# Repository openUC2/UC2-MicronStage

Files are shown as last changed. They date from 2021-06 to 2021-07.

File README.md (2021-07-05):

<p align="left">

</p>

# openUC2 MicronStage
---

This repository will help you to set up a very simple yet powerful xy-stage for your UC2-based microscope experiments, where manipulating the region of interest (ROI) in X/Y at a micrometer level using NEMA stepper motors becomes important.

The electronics are based on the [GRBL](https://github.com/grbl/grbl)-firmware and can be controlled either through an Arduino Shield (e.g. CNC Shield v3) controlled by a Raspberry Pi/Nvidia Jetson/laptop or a dedicated CNC/3D printing electronics (e.g. MKS CLS). Curious to see what this looks like? Keep scrolling!

<p align="center">
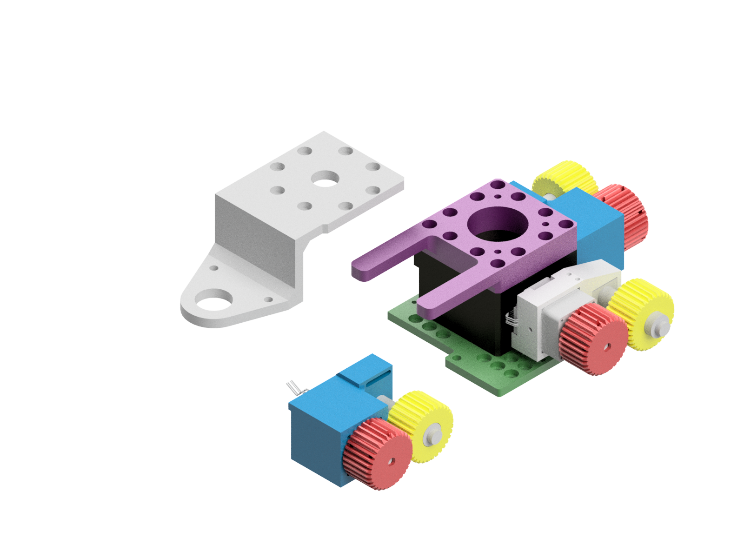
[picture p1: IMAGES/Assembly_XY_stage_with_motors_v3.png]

</p>

This stage can be used for diffrent experiments. We have successfully used it for Ptychography, where micrometer stage manipulation is of importance. Similarly, we use it for autonomously operating fluorescence microscopes. A complete tutorial can be found in the [core UC2 repository](https://github.com/openUC2/UC2-GIT/tree/master/APPLICATIONS/APP_Fluorescence_Microscope_infinity)

Depending on the settings of the [GRBL](https://github.com/grbl/grbl)-controller you can achieve <1µm resolution with the stage! Adding an additional optical encoder by means of a camera (e.g. Raspicam) + microscope objective lens, the open-loop stage can be used as a closed-loop stage with very high precision. More about this will follow soon!

The overall price is in the range under 300€.

The stage on top of a fluorescence microscope:

<p align="center">

</p>

***Features:***

- Move samples plate in XY at high resolution
- NEMA11-based mechanism
- Fast scanning
- Very precise
- Whole setup <300€ in parts
- Easy to assemble
- Limited number of parts (3D printed + off-the-shelf components)
- Minimum of tools required
- Use GRBL as the motion protocol

# Table of Content

- **[Electronics](#-electronics)**
- **[Software](#-software)**
- **[Hardware](#-hardware)**
- **[Bill of materials](#-results)**
- **[Results](#-results)**

## In-Action

You can directly control the microscope from the Opentrons Jupyter notebook. We have collected some notebooks showing its control in the folder [./PYTHON](./PYTHON). This way it becomes very simple to plan experiments which involve both, pipetting and imaging.

<p align="center">

</p>

# SOFTWARE

We offer different ways to control the stage!

## Openflexure

**Warning:** This is still under strong development. We derived the software to control the GRBL-based XYZt stage from the [Openflexure microscope project](https://gitlab.com/beniroquai/openflexure-microscope-server) by Bowman et al.
Instead of using a Raspberry Pi camera, we use an Nvidia Jetson Nano singleboard computer and run a customized version of the OFM server that can control the GRBL board and the monochrome CMOS camera.

A detailed set of instructions for installing the Openflexure Server (OFM Server) will be found in a dedicated README_SOFTWARE.md (it is under construction...). In case you want a preinstalled image, please contact us!

## Octopi-Research

We have written a small device adapter for the Octopi research developed for the SQUID project from the [PrakashLab](https://squid-imaging.org/7bad36b7a9b44cacb1fe1580b39e05d8).
Please have a look in this [repository](https://github.com/beniroquai/octopi-research)

## Custom Python code

We also provide a small code example for driving the code using a python driver. Please refer to the Jupyter Notebook and the package in the folder [PYTHON](./PYTHON).

# HARDWARE

Below we describe how the XY Stage can be build and assembled in order to replicate the whole system as shown in the rendering above. One needs additional parts that can be found in the original [openUC2 repository](https://github.com/bionanoimaging/UC2-GIT).

## Bill of material

Below you will find all components necessary to build this device

### 3D printing files

All these files need to be printed. We used a Prusa i3 MK3 using PLA Prusament (Galaxy Black) at layer height 0.3 mm and infill 80%.

|  Type | Details  |  Price | Link  |
|---|---|---|---|
| Sample Holder |  (optional) Sample holder with lowered base which adapts to XY stage |  0.04 € | [Assembly_XY_stage_with_motors_v3_cellSTORM_UC2_Sample_arm_ptycho.stl](./STL/Assembly_XY_stage_with_motors_v3_cellSTORM_UC2_Sample_arm_ptycho.stl)  |
| Sample Holde | Sample holder with staight base which adapts to XY stage  |  4 € | [Assembly_XY_stage_with_motors_v3_30_XY_Sample_arm_v3.stl](./STL/Assembly_XY_stage_with_motors_v3_30_XY_Sample_arm_v3.stl)  |
| Baseplate | Adapts the XY-stage to the UC2 cubes |  4 € | [Assembly_XY_stage_with_motors_v3_cellSTORM_UC2_Laser_base.stl](./STL/Assembly_XY_stage_with_motors_v3_cellSTORM_UC2_Laser_base.stl)  |
| Motor mount | Adapts the motor to the stage |  4 € | [Assembly_XY_stage_with_motors_v3_30_Mount_Nema_Motor_attachement_for_XYstage_v3.stl](./STL/Assembly_XY_stage_with_motors_v3_30_Mount_Nema_Motor_attachement_for_XYstage_v3.stl)  |
| Gear 2 | Gear for micrometer screw |  4 € | [Assembly_XY_stage_with_motors_v3_cellSTORM_UC2_motorized_micrometer_gear2_1.stl](./STL/Assembly_XY_stage_with_motors_v3_cellSTORM_UC2_motorized_micrometer_gear2_1.stl)  |
| Gear 1 | Gear for motor |  4 € | [Assembly_XY_stage_with_motors_v3_cellSTORM_UC2_motorized_micrometer_gear1_2.stl](./STL/Assembly_XY_stage_with_motors_v3_cellSTORM_UC2_motorized_micrometer_gear1_2.stl)  |

### Additional parts

#### XY Stage from Aliexpress

We tested many different variants, where many were not really reproducible by means of whole positions and linear guiding quality. Finally we decided to buy a couple of these stages and are very happy with them!
The `XY60-C` costs between 40-50€ and compares to a `Thorlabs LX20`stage (820€).

<p align="center">

</p>

It is available from this [Aliexpress shop](https://de.aliexpress.com/item/4000801621380.html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,searchweb201602_,searchweb201603). Search for "XY Axis 60*60mm Trimming Station Manual Displacement Platform Linear Stage Sliding Table XY60-C XY60-R,XY60-LM LY60 Cross Rail"

From the website the following information is available:

***Feature:***

```
1. Using mobile cross roller guides, enabling high-precision, smooth
2. The main body made of aluminum alloy, light weight, suitable to be built for other devices
```

***Parameter:***
```
1. Direction of movement: X Y axis direction
2. Body material: Aluminium
3. Drive: differential head
4. The table size: 60x60mm
5. Table thickness: 36mm/30mm
6. Stroke: ± 6.5mm（Customizable ±12.5,if you need,contact us）
7. Load: 49N (5kgf)
8. Minimum scale: 0.01mm
9. Accuracy class: 0.01mm
10. Parallelism: 0.06mm
11. Weight: 0.48kg
```

#### Additional parts

This is used in the current version of the setup

|  Type | Details  |  Price | Link  |
|---|---|---|---|
| MKS DLC CNC  (NEMA Motors) | Controller Electronics for NEMA motors and Laser |  25 € | [Roboter-Baukasten](https://www.roboter-bausatz.de/p/mks-dlc-cnc-lasergravierer-mainboard-grbl)  |
| M3, M4 Screws | Screw Set |  12 € | [Ebay](https://www.ebay.de/itm/Schrauben-Set-520tlg-Edelstahl-Schrauben-Muttern-M3-M4-M5-Linsenkopfschrauben/383726480774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)  |
| yourDroid Netzteil 12V 3A 5,5x2,1mm DC-Stecker | Power  Supply 12V |  6,45 € | [Roboter-Baukasten](https://www.roboter-bausatz.de/)  |
| 3x A4988 Schrittmotorentreiber	RBS10232 | Stepper Driver |  0,99 € | [Roboter-Baukasten](https://www.roboter-bausatz.de/)  |
| Spring | Diameter: 5mm, 15mm long |  0,99 € | [Roboter-Baukasten](https://www.roboter-bausatz.de/)  |
| Nema11 Motor | Steppermotor |  23 € | [Eckstein](https://eckstein-shop.de/Pololu-Stepper-Motor-NEMA-11-Bipolar-200-Steps-Rev-2832mm-38V-067-A-Phase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)  |

### Assembly of the XY Stage

***1.*** *These are the parts needed for the XY-stage*

<p align="center">
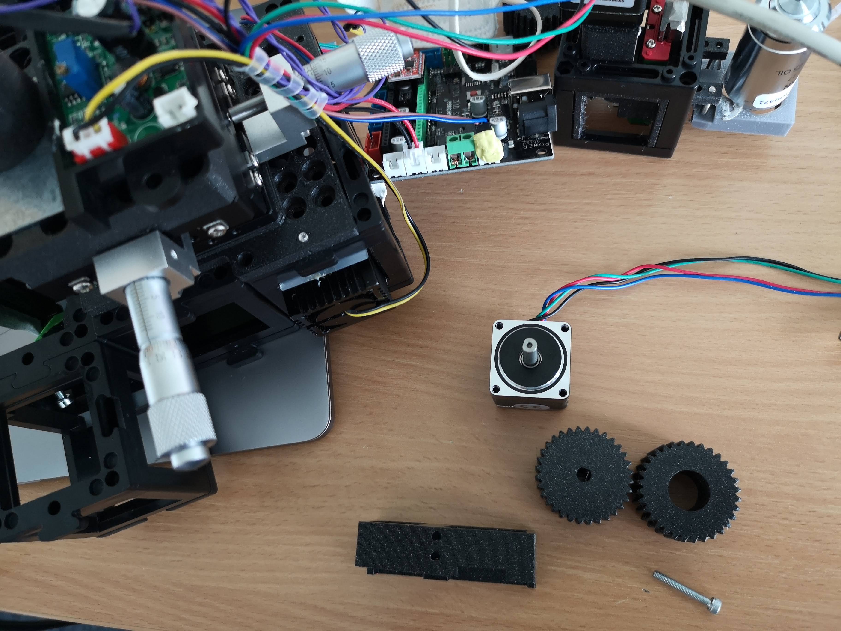
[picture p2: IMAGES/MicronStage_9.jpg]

</p>

***2.*** *Start by removing the micrometre with the screws for one axis*

<p align="center">
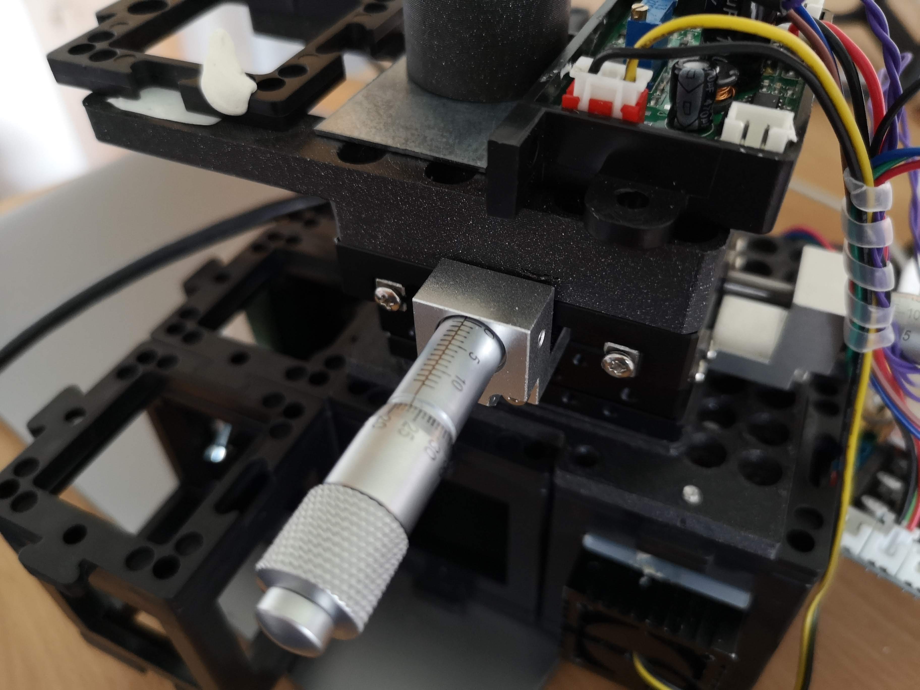
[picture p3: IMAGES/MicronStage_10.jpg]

</p>

***3.*** *Try to add something which blocks the rail from snapping back (e.g. screwdriver)*

<p align="center">
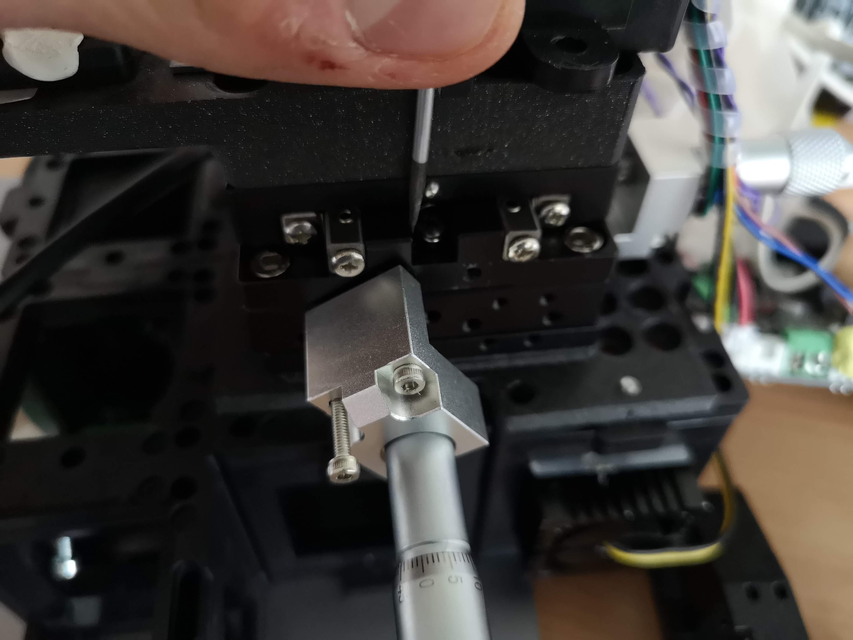
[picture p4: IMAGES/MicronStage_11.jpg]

</p>

***4.*** *Add the micrometer screw to the motor adapter ad add a screw at a side to mount it (M3x8mm)*

<p align="center">
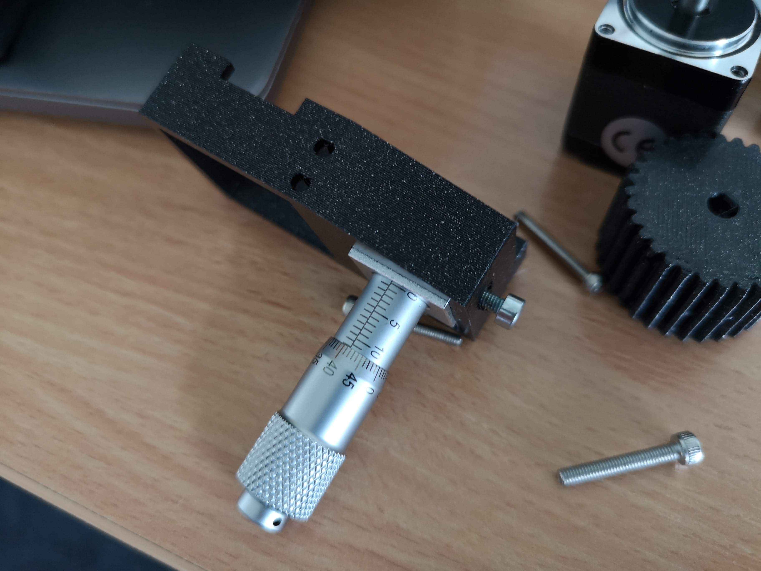
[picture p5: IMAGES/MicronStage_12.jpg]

</p>

***5.*** *Add the motor to the adapter*

<p align="center">
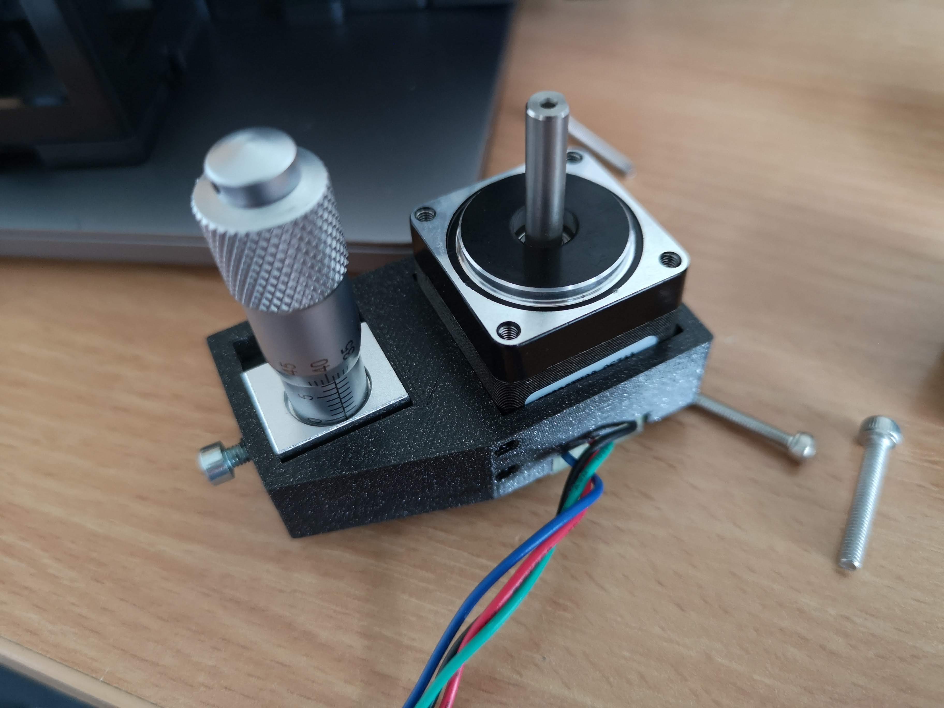
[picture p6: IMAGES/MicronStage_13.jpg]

</p>

***5.1 (optional)*** *Add M3 screws to have a better mounting of the motor*

<p align="center">
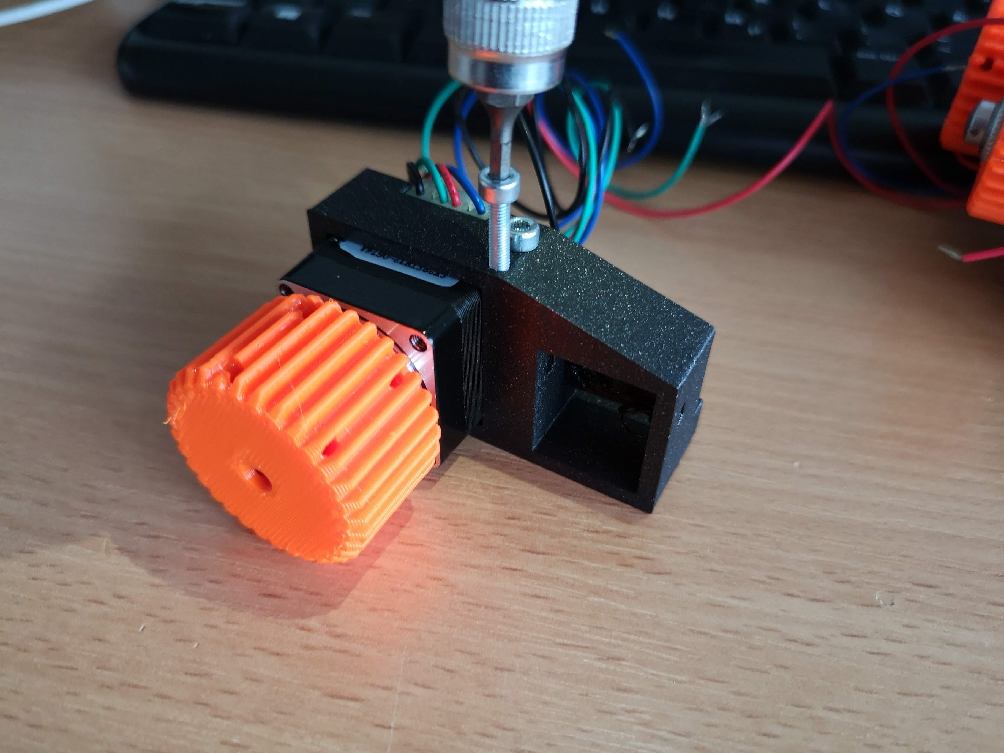
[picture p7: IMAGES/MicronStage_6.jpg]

</p>

***6.*** *Mount the gears*

<p align="center">
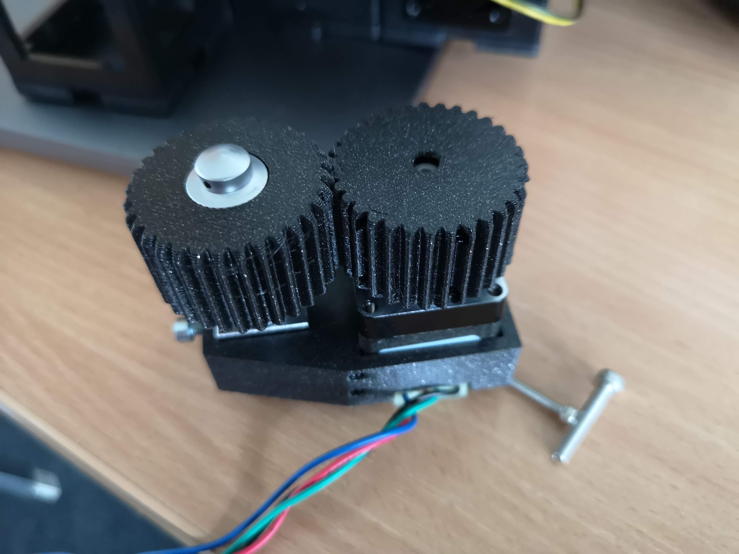
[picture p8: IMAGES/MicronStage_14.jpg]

</p>

***6.1*** *Fix the gears with screws (M3 - headless)*
<p align="center">
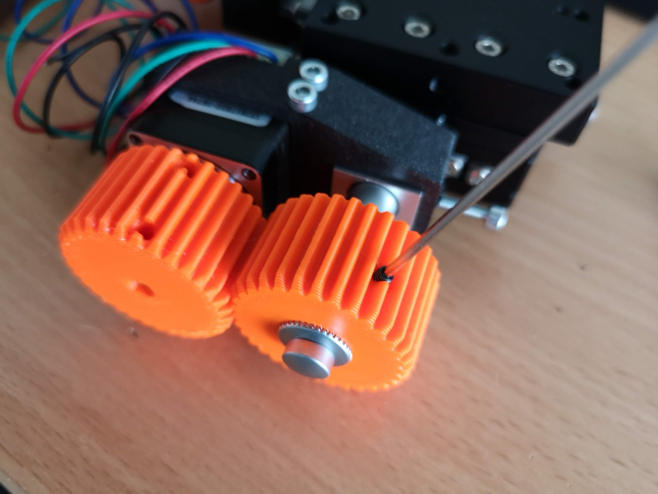
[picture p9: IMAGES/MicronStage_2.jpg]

</p>

***7.*** *Mount the assembly back on the XY-stage with the M2.5 screws*

<p align="center">
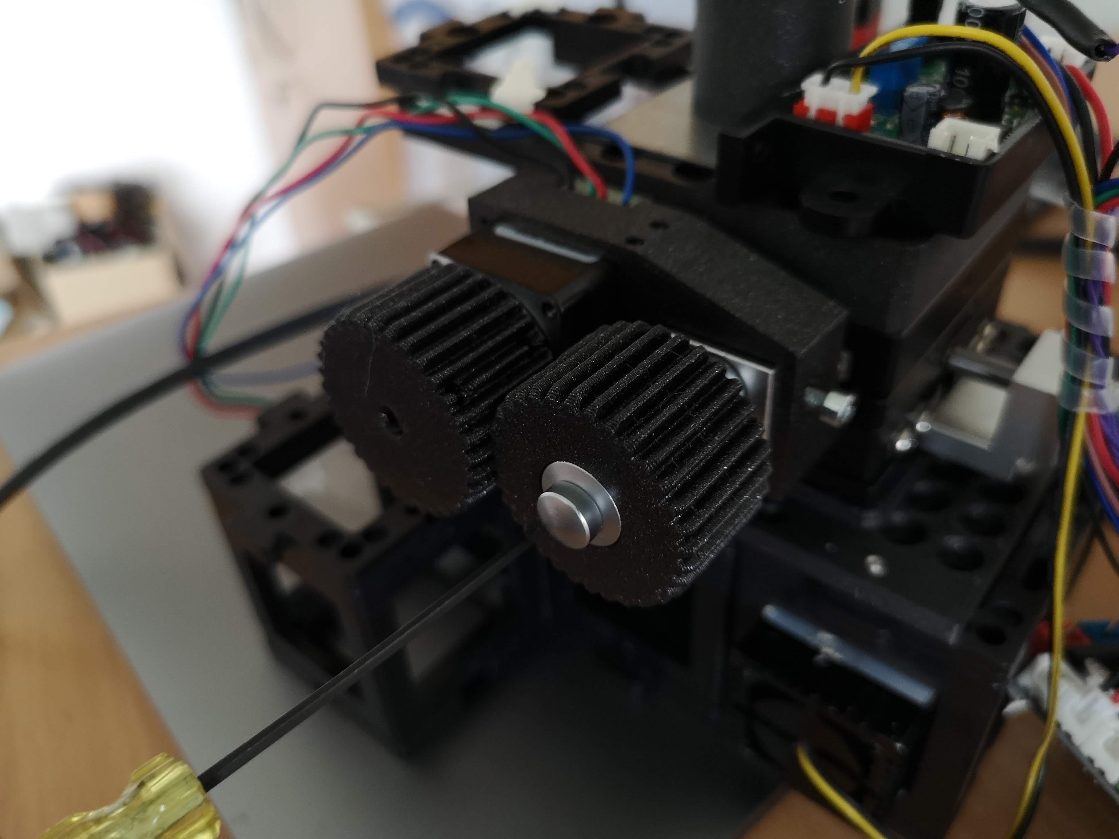
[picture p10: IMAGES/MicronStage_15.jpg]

</p>

***7.1*** *Does it look like this?*
<p align="center">
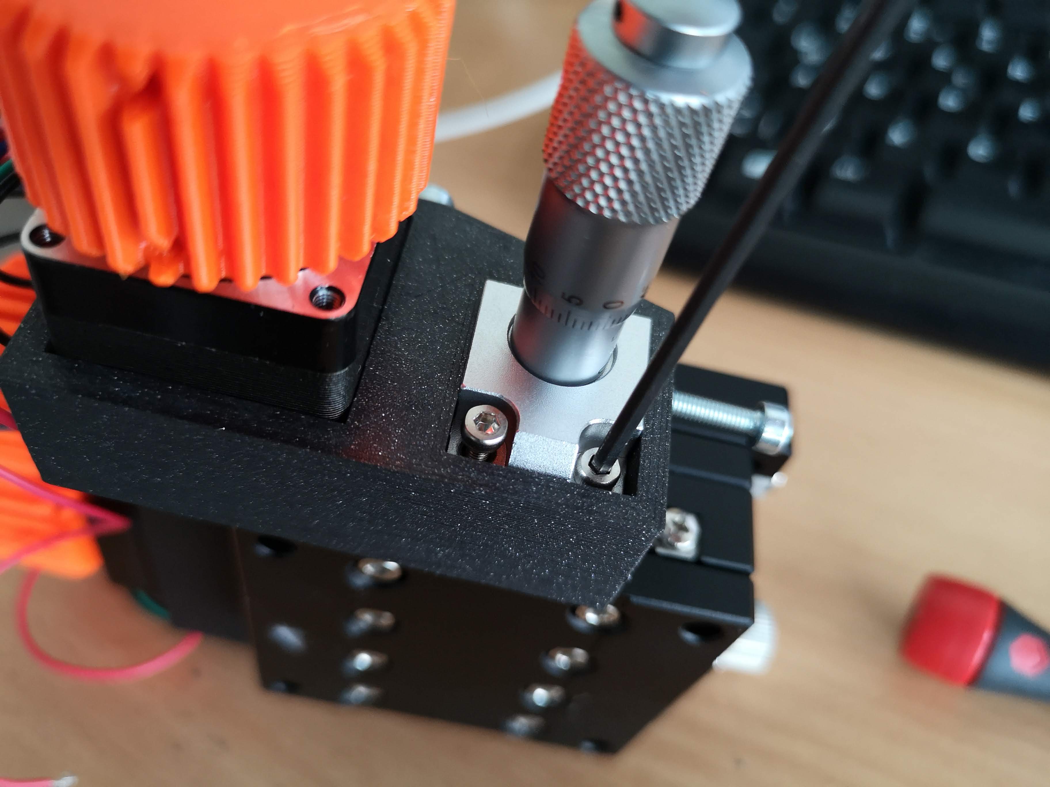
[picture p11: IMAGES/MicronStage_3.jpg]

</p>

***8.*** *Repeat it for the second axis and mount the sample adapter (M4)*

<p align="center">
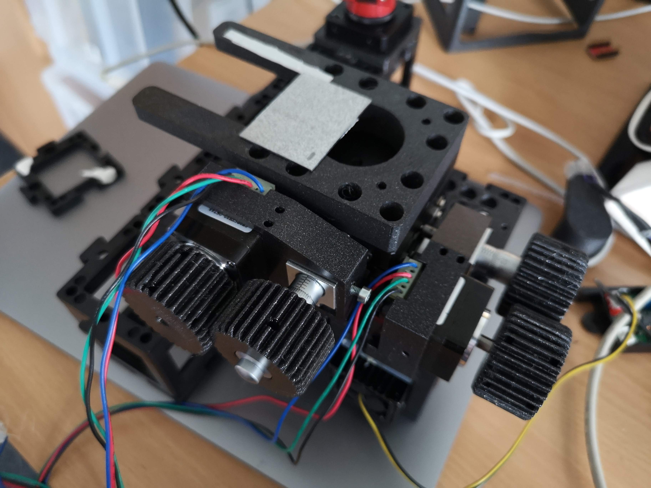
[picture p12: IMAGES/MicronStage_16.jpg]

</p>

***9. (optional)*** *Add the printed baseplate to the XY-stage - then screw the UC2 puzzle-piece baseplates to the printed baseplate of the XY-stage*

<p align="center">
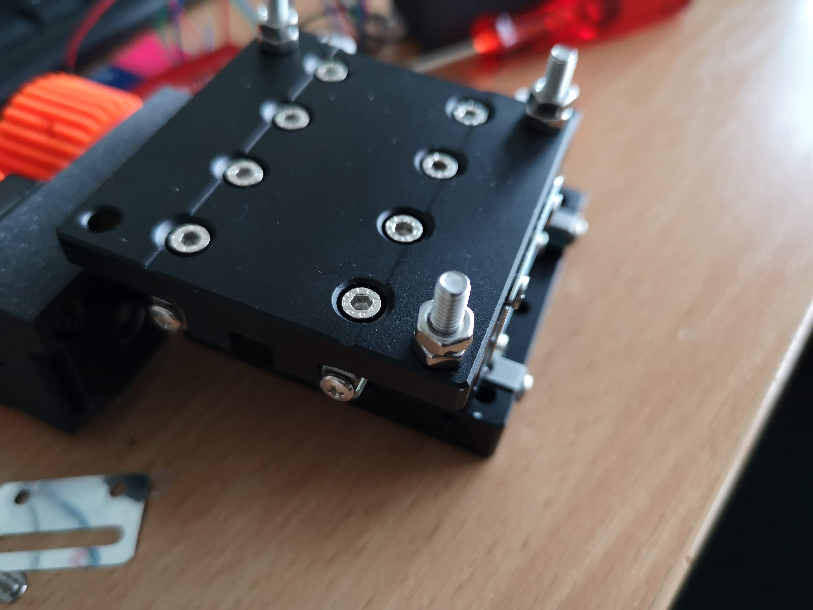
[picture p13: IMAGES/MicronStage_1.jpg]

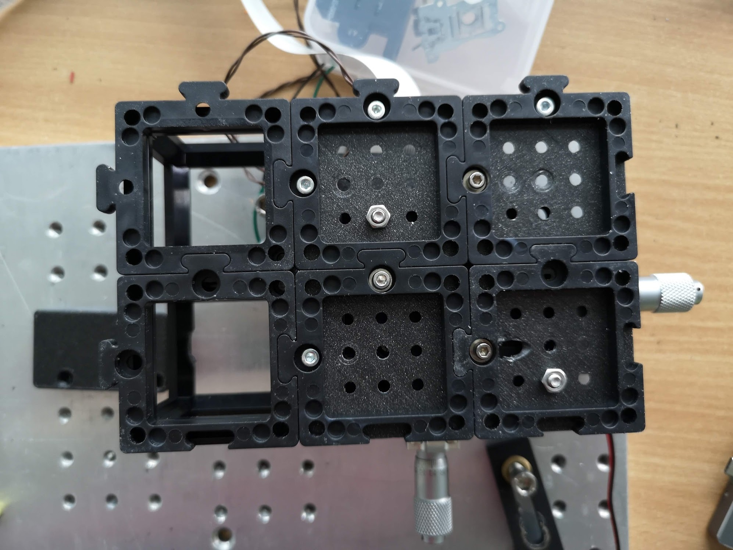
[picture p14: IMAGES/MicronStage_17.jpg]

</p>

## Showcase

Some results will show up here soon.

<p align="center">

</p>

***Fig 1.*** *Fluorescent cells (HeLa) moved in XY/Z This is actually a very bad example ;-)*

<p align="center">

</p>

***Fig 2.*** *Ptychography measurements of a USAF chart scanned through a beam*

## Get Involved

This project is open so that anyone can get involved. You don't even have to learn CAD designing or programming. Find ways you can contribute in  [CONTRIBUTING](https://github.com/openUC2/UC2-GIT/blob/master/CONTRIBUTING.md)

## License and Collaboration

This project is open-source and is released under the CERN open hardware license. Our aim is to make the kits commercially available.
We encourage everyone who is using our Toolbox to share their results and ideas, so that the Toolbox keeps improving. It should serve as a easy-to-use and easy-to-access general purpose building block solution for the area of STEAM education. All the design files are generally for free, but we would like to hear from you how is it going.

You're free to fork the project and enhance it. If you have any suggestions to improve it or add any additional functions make a pull-request or file an issue.

Please find the type of licenses [here](https://github.com/openUC2/UC2-GIT/blob/master/License.md)

REMARK: All files have been designed using Autodesk Inventor 2019 (EDUCATION)

## Collaborating
If you find this project useful, please like this repository, follow us on Twitter and cite the webpage! :-)

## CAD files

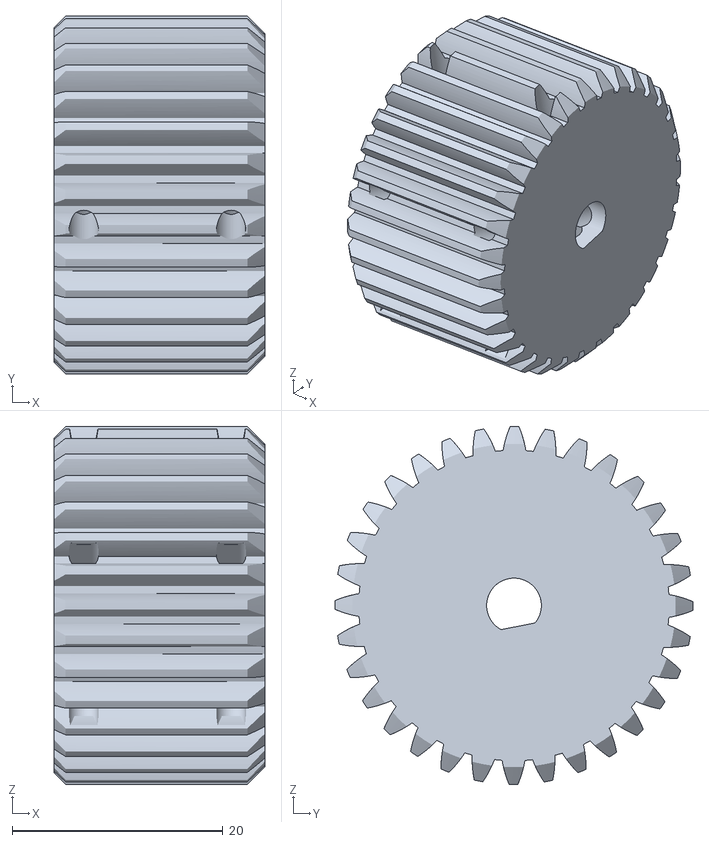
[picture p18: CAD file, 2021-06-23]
STL/Assembly_XY_stage_with_motors_v3_cellSTORM_UC2_motorized_micrometer_gear1_2.stl
20.0 x 34.0 x 34.0

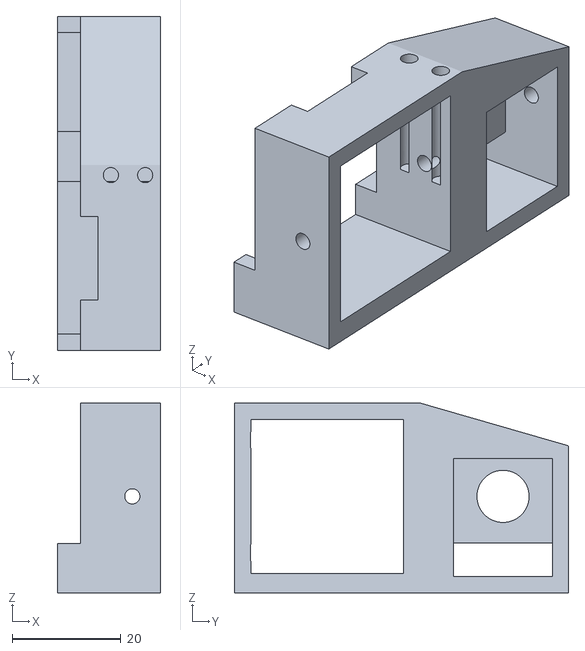
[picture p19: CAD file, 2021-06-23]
STL/Assembly_XY_stage_with_motors_v3_30_Mount_Nema_Motor_attachement_for_XYstage_v3.stl
19.0 x 61.6 x 35.0

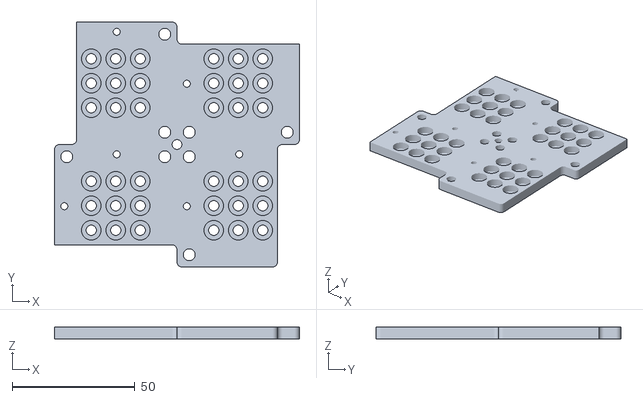
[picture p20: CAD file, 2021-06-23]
STL/Assembly_XY_stage_with_motors_v3_cellSTORM_UC2_Laser_base.stl
100.0 x 100.0 x 5.00

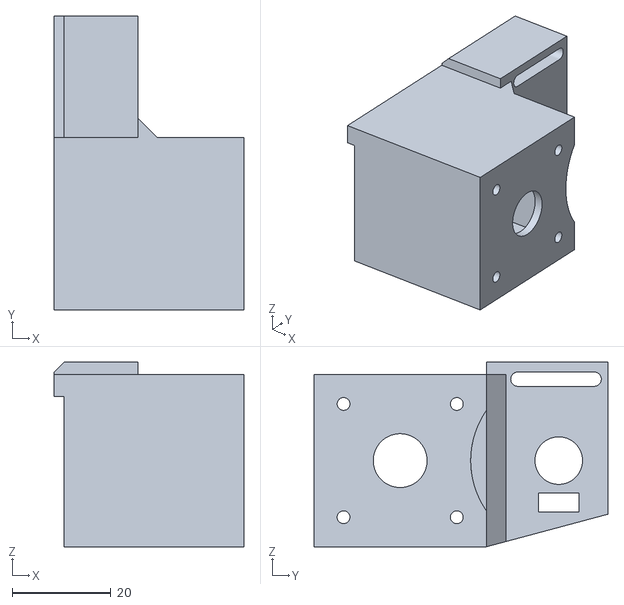
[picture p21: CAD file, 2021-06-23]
STL/Assembly_XY_stage_with_motors_v3_cellSTORM_UC2_motorized_micrometer_motormount_1.stl
38.5 x 59.7 x 37.5

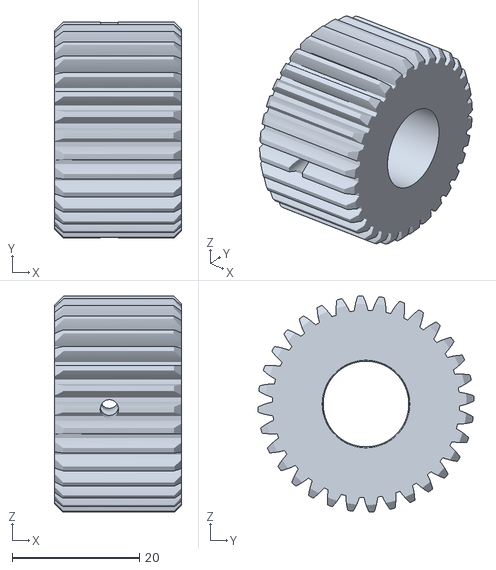
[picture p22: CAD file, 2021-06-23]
STL/Assembly_XY_stage_with_motors_v3_cellSTORM_UC2_motorized_micrometer_gear2_1.stl
20.0 x 34.0 x 34.0

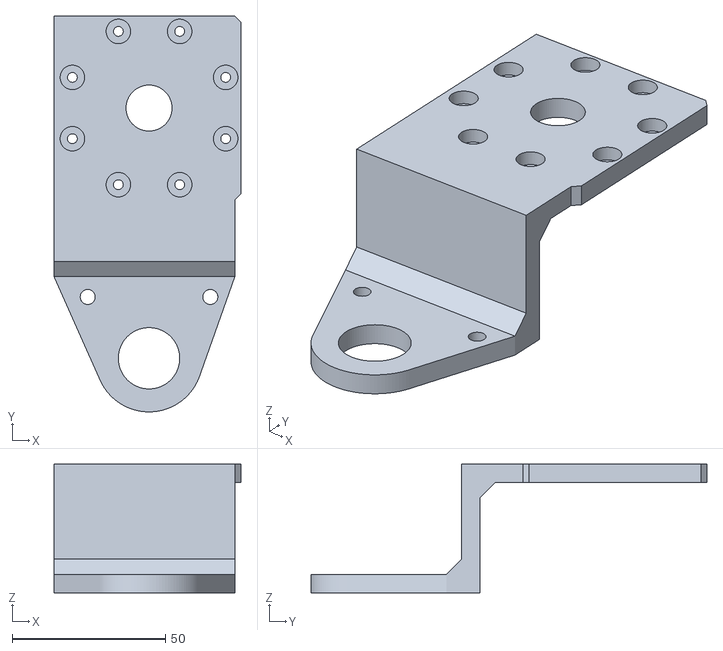
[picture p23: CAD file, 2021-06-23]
STL/Assembly_XY_stage_with_motors_v3_cellSTORM_UC2_Sample_arm_ptycho.stl
61.0 x 129.1 x 42.0

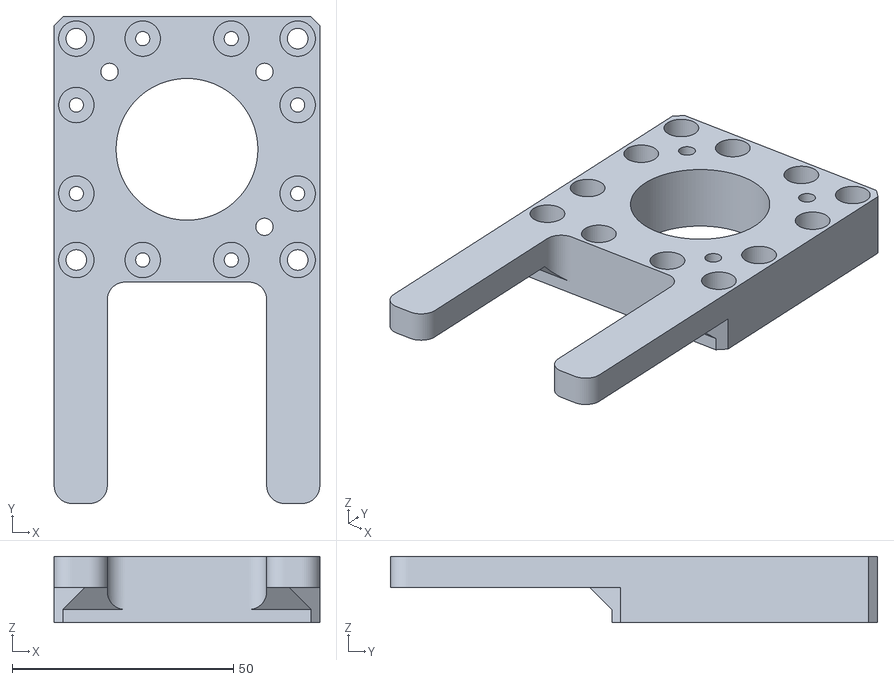
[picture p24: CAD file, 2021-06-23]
STL/Assembly_XY_stage_with_motors_v3_30_XY_Sample_arm_v3.stl
60.0 x 110.0 x 15.0

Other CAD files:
INVENTOR/00_NEMA11.ipt
INVENTOR/00_XY_stage-CHUO_SEIKI_LD-647-R1-Bottom.ipt
INVENTOR/00_XY_stage-CHUO_SEIKI_LD-647-R1-Middle.ipt
INVENTOR/00_XY_stage-CHUO_SEIKI_LD-647-R1-Top.ipt
INVENTOR/00_XY_stage-CHUO_SEIKI_LD-647-R1.iam
INVENTOR/00_micrometer_moun_xystage_china.ipt
INVENTOR/00_micrometer_xy-stage.ipt
INVENTOR/30_Mount_Nema_Motor_attachement_for_XYstage_v3.ipt
INVENTOR/30_XY_Sample_arm_v3.ipt
INVENTOR/Assembly_Nema_Motor_attachement_for_XYstage.iam
INVENTOR/Assembly_XY_stage_with_motors_v3.iam
INVENTOR/cellSTORM_UC2_Laser_base.ipt
INVENTOR/cellSTORM_UC2_Sample_arm_ptycho.ipt
INVENTOR/cellSTORM_UC2_motorized_micrometer.iam
INVENTOR/cellSTORM_UC2_motorized_micrometer_gear1.ipt
INVENTOR/cellSTORM_UC2_motorized_micrometer_gear2.ipt
INVENTOR/cellSTORM_UC2_motorized_micrometer_motormount.ipt
INVENTOR/cellSTORM_UC2_motorized_xystage_spacer.ipt

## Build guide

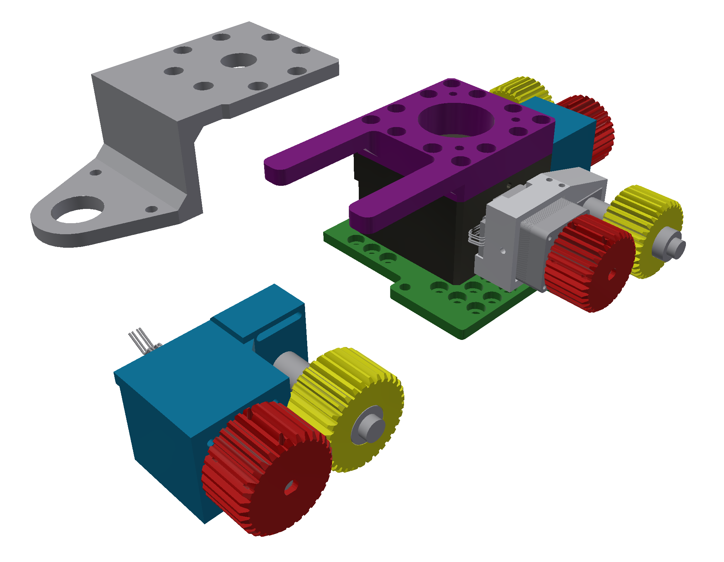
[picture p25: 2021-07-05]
IMAGES/Assembly.PNG

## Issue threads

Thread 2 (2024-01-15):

XY -> XYZ

pchiang5, 2024-01-15:
Hello,

Thank you for the interesting project!
Can the scripts and printed components be modified to make the stage 3D using the XYZ stage (below) similar to the XY one?

https://de.aliexpress.com/item/1005004987973842.html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,scm-url:1007.13339.291025.0,pvid:15d74850-6028-43e3-ba00-cb49a406079c,tpp_buckets:668%232846%238110%231995&pdp_npi=4%40dis%21TWD%2110539.23%214953.42%21%21%21338.98%21159.32%21%402101efac17053036923696228e9de3%2112000031252753360%21rec%21TW%21%21AB&utparam-url=scene%3ApcDetailBottomMoreThisSeller%7Cquery_from%3A

beniroquai, 2024-01-15:
Hey, unfortunately the part cannot be visualized:
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

Can you perhaps send a screenshot?

pchiang5, 2024-01-15:
My apologies. Please see attached.

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

beniroquai, 2024-01-15:
Yes. That should work. How do you envision to mount the stage?

pchiang5, 2024-01-15:
Great!

I would like to use the epifluorescence model below, replacing the xy + z with this XYZ (+- 12.5mM).
https://github.com/openUC2/UC2_Fluorescence_microscope

beniroquai, 2024-01-18:
Cool idea. Do you already have the setup ready? Not sure how you wanted to mount the stage on the cubes yet :)

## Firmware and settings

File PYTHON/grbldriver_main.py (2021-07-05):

# -*- coding: utf-8 -*-
"""
Created on Fri Jun 25 11:19:06 2021

@author: diederichbenedict
"""
print("Programme started!")
import grbldriver as grbldriver # library for the xy arm

port = "COM10"
board = grbldriver.GrblDriver(port)
print("Board conected.")

board.write_global_config()
board.reset_stage()
# board.is_debug=True

#%%

stpsmm = 16250

board.xconfig ={
            # 'steps/mm':360/1.8*diameter/2., #<--resolutoin
            'steps/mm':stpsmm, #<--resolutoin
            'mm/sec2': 100.0, #<--acceleration
            'mm/min': 10 #<--max speed
            }
board.yconfig ={
            'steps/mm':stpsmm, #<--resolutoin
            'mm/sec2': 100.0, #<--acceleration
            'mm/min': 10 #<--max speed
            }

board.zconfig ={
            'steps/mm':stpsmm, #<--resolutoin
            'mm/sec2': 1000.0, #<--acceleration
            'mm/min': 10 #<--max speed
            }


print("Config saved")
board.write_all_settings()
print("Config wrote")


#%%
board.move_rel((-100,-100,00), wait_until_done=True)


#%%
board.move_rel((0,0,1000), wait_until_done=True)

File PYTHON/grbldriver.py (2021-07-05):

import serial
import time
import re
import numpy as np

class GrblDriver:
    """Class for interfacing with GRBL loaded on an Arduino Uno.Arduino

    NOTE: GRBL config.h had to be modified in order to make GRBL v1.1 compatible
    with the arduino shield (https://blog.protoneer.co.nz/arduino-cnc-shield/).
    Pin D12 is by default used for spindle control.  Comment the line (line339)
    to disable spindle control so that z-limit switch is on the right pin.

    ''' OPTIMAL SETTINGS:
        ok
        >>> $$
        $0 = 10    (Step pulse time, microseconds)
        $1 = 255    (Step idle delay, milliseconds)
        $2 = 144    (Step pulse invert, mask)
        $3 = 0    (Step direction invert, mask)
        $4 = 0    (Invert step enable pin, boolean)
        $5 = 0    (Invert limit pins, boolean)
        $6 = 0    (Invert probe pin, boolean)
        $10 = 2    (Status report options, mask)
        $11 = 0.010    (Junction deviation, millimeters)
        $12 = 0.000    (Arc tolerance, millimeters)
        $13 = 0    (Report in inches, boolean)
        $20 = 0    (Soft limits enable, boolean)
        $21 = 0    (Hard limits enable, boolean)
        $22 = 1    (Homing cycle enable, boolean)
        $23 = 0    (Homing direction invert, mask)
        $24 = 50.000    (Homing locate feed rate, mm/min)
        $25 = 100.000    (Homing search seek rate, mm/min)
        $26 = 250    (Homing switch debounce delay, milliseconds)
        $27 = 0.100    (Homing switch pull-off distance, millimeters)
        $30 = 1000    (Maximum spindle speed, RPM)
        $31 = 0    (Minimum spindle speed, RPM)
        $32 = 0    (Laser-mode enable, boolean)
        $100 = 780.000    (X-axis travel resolution, step/mm)
        $101 = 780.000    (Y-axis travel resolution, step/mm)
        $102 = 5000.000    (Z-axis travel resolution, step/mm)
        $110 = 200.000    (X-axis maximum rate, mm/min)
        $111 = 200.000    (Y-axis maximum rate, mm/min)
        $112 = 200.000    (Z-axis maximum rate, mm/min)
        $120 = 10.000    (X-axis acceleration, mm/sec^2)
        $121 = 10.000    (Y-axis acceleration, mm/sec^2)
        $122 = 5000.000    (Z-axis acceleration, mm/sec^2)
        $130 = 200.000    (X-axis maximum travel, millimeters)
        $131 = 200.000    (Y-axis maximum travel, millimeters)
        $132 = 200.000    (Z-axis maximum travel, millimeters)
        ok
        **** Connection closed ****
    """
    
    
    def __init__(self, address='/dev/ttyACM0'):
        self.ser = serial.Serial(address, baudrate=115200, timeout=0.01)
        self.waittimeout = 0.01
        self.is_debug = False
        
        # illumination settings
        self.laser_intensity = 0
        self.led_state = 0
        self.positions = (0,0,0)
        self.stepdivider = 1000
        self.speed = 10000

        #initialize and wait for grbl to wake up
        self._write('\r\n\r\n')
        time.sleep(2)
        self.ser.reset_input_buffer()

        # x-motor configuration
        self.xconfig = {
            'steps/mm':1300., #<--resolutoin
            'mm/sec2': 10, #<--acceleration
            'mm/min': 200 #<--max speed
            }
        
        #map x settings to grbl commands
        self.xsettingsmap = {
            'steps/mm':'$100',
            'mm/min':'$110', #max rate, not constant speed
            'mm/sec2':'$120' #accel
        }

        # y-motor configuration
        self.yconfig = {
            'steps/mm':1300., #<--resolutoin
            'mm/sec2': 10, #<--acceleration
            'mm/min': 200 #<--max speed
            }
        
        #map y settings to grbl commands
        self.ysettingsmap = {
            'steps/mm':'$101',
            'mm/min':'$111', #max rate, not constant speed
            'mm/sec2':'$121' #accel
        }

        # Z-motor configuration
        self.zconfig = {
            'steps/mm':5000, #<--resolutoin
            'mm/sec2': 200, #<--acceleration
            'mm/min': 200 #<--max speed
            }
            
        #map z settings to grbl commands
        self.zsettingsmap = {
            'steps/mm':'$102',
            'mm/min':'$112', #max rate, not constant speed
            'mm/sec2':'$122' #accel
        }

        #internal, to write to fit into grbl's interface
        self._update_writesettings()

        self.globalconfig = {
            1:255, #ms to wait before going idle (255=don't disable steppers)
            5:0,  #set NO limit switch
            20:0, # enable soft limit switch (stop immediately) # changed to off 1.31.19 after crash during data collection
            21:0, # enable hard limit switch (stop immediately) # changed to off 1.31.19 after crash during data collection
            22:1, # enable homing cycle
            24:50, # homing speed fine
            25:100, # homing speed
            3:0,    # inverse Direction of X motor
            27:0.1, # (Homing switch pull-off distance, millimeters)
            30:1024, # resolution PWM
            31:0, # minimum spindle speed
            32:0# enable laser mode 


        }
        
    def _update_writesettings(self):
        self.xwritesettings={
            'steps/mm':self.xconfig['steps/mm'],
            'mm/min':self.xconfig['mm/min'],
            'mm/sec2':self.xconfig['mm/sec2']
        }
        self.ywritesettings={
            'steps/mm':self.yconfig['steps/mm'],
            'mm/min':self.yconfig['mm/min'],
            'mm/sec2':self.yconfig['mm/sec2']
        }
        self.zwritesettings={
            'steps/mm':self.zconfig['steps/mm'],
            'mm/min':self.zconfig['mm/min'],
            'mm/sec2':self.zconfig['mm/sec2']
        }
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

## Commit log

2021-06-23 Initial Commit of the UC2 micronstage
    [00_NEMA11.ipt, 00_XY_stage-CHUO_SEIKI_LD-647-R1-Bottom.ipt, 00_XY_stage-CHUO_SEIKI_LD-647-R1-Middle.ipt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]
2021-07-05 Adding driver for Ender-Syringe.
